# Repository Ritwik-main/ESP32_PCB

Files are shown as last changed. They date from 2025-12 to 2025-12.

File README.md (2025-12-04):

# ESP32_PCB
DesignESP32PCB

# A pcb using espressif ESP32-S3-DEV
This project involves making a devboard using the ESP32-s3 module by Espressif.
We know ESP are the go-to microcontrollers when we want speed and integrated Wifi Bluetooth in out projects.








# Features
1. Fully designed in KiCad
2. Features a USB-C USB 2.0 for convenience
3. ESP32 DevBoard features a design under 100*100mm, making it ideal for production houses.
4. 2-Layer PCB
5. Built in AdaFruit NeoPixel as an actuator
6. Built in Zero-PCB/protoboard with ~600 holes to make deployment after prorotype as easy as it can get!

# Main components used
1. Espressif ESP32-S3-Mini-N8
2. Adafruit Neopixel 5mm
3. Texas Instruments tlv758p
4. USB-C 2.0

# Schematic
Designed in KiCad


# resources I used for this project:
1. https://docs.espressif.com/projects/esp-hardware-design-guidelines/en/latest/esp32s3/esp-hardware-design-guidelines-en-master-esp32s3.pdf
2. https://docs.espressif.com/projects/esp-idf/en/stable/esp32s3/get-started/index.html
3. https://www.ti.com/lit/ds/symlink/tlv758p.pdf?ts=1764750861284
4. https://documentation.espressif.com/esp32-s3_technical_reference_manual_en.pdf
5. https://cdn-shop.adafruit.com/datasheets/WS2812B.pdf

# Developer note:
If you do manufacture this PCB, when you get it for the first time, it is necessary to do the initialization boot sequence when esp is powered.
hold boot> click reset once> release boot
This allows ESP to go into coding mode where you can upload code into your board.

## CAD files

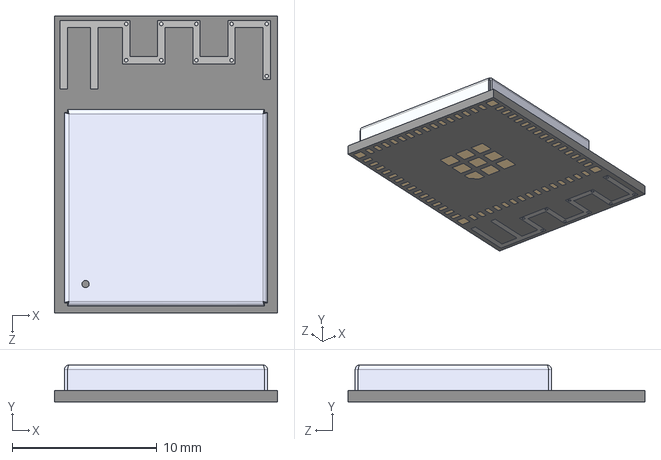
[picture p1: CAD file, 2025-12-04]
ESP32_S3_MINI_1_N8/ESP32-S3-MINI-1-N8.step
15.4 x 2.55 x 20.5 mm

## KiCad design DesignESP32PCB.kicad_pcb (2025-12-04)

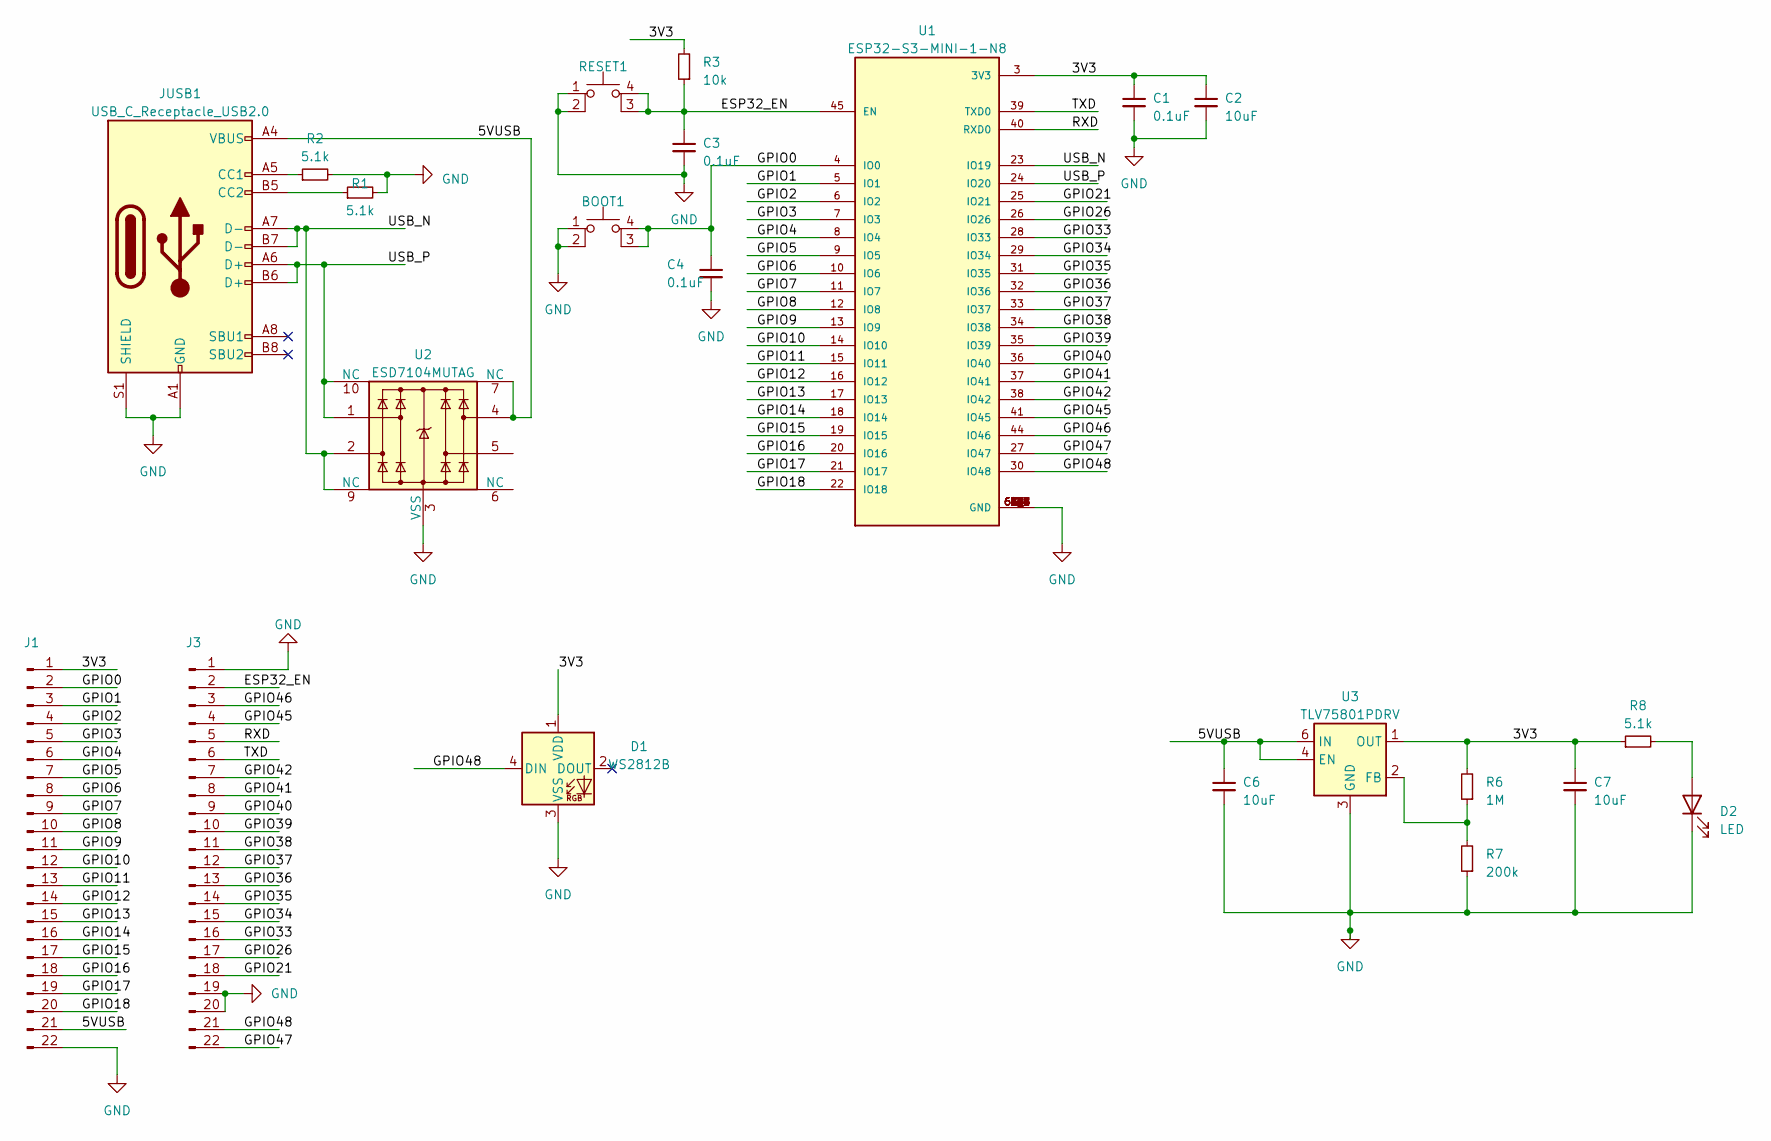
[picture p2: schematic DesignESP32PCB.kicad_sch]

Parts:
BOOT1: SW_SPST_PTS810
C1, C3, C4: 0.1uF; C_0603_1608Metric
C2, C6, C7: 10uF; C_0603_1608Metric
D1: WS2812B; LED_WS2812B_PLCC4_5.0x5.0mm_P3.2mm
D2: LED; LED_0603_1608Metric
J1, J3: PinHeader_1x22_P2.54mm_Vertical
JUSB1: USB_C_Receptacle_USB2.0; USB_C_Receptacle_GCT_USB4105-xx-A_16P_TopMnt_Horizontal
R1, R2, R8: 5.1k; R_0603_1608Metric
R3: 10k; R_0603_1608Metric
R6: 1M; R_0603_1608Metric
R7: 200k; R_0603_1608Metric
RESET1: SW_SPST_PTS810
U1: ESP32-S3-MINI-1-N8; XCVR_ESP32-S3-MINI-1-N8; PARTREV v0.6
U2: ESD7104MUTAG; Diodes_UDFN-10_1.0x2.5mm_P0.5mm
U3: TLV75801PDRV; WSON-6-1EP_2x2mm_P0.65mm_EP1x1.6mm

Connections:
/3V3: C1.1, C2.1, C7.1, D1.1 (VDD), J1.1, R3.2, R6.2, R8.1, U1.3 (3V3), U3.1 (OUT)
/5VUSB: C6.1, J1.21, JUSB1.A4 (VBUS), JUSB1.A9 (VBUS), JUSB1.B4 (VBUS), JUSB1.B9 (VBUS), U2.4, U2.7 (NC), U3.4 (EN), U3.6 (IN)
/ESP32_EN: C3.1, J3.2, R3.1, RESET1.3 (K), RESET1.4 (A), U1.45 (EN); also elsewhere on the board
/GPIO0: BOOT1.3 (K), BOOT1.4 (A), C4.1, J1.2, U1.4 (IO0); also elsewhere on the board
/GPIO1: J1.3, U1.5 (IO1)
/GPIO2: J1.4, U1.6 (IO2)
/GPIO3: J1.5, U1.7 (IO3)
/GPIO4: J1.6, U1.8 (IO4)
/GPIO5: J1.7, U1.9 (IO5)
/GPIO6: J1.8, U1.10 (IO6)
/GPIO7: J1.9, U1.11 (IO7)
/GPIO8: J1.10, U1.12 (IO8)
/GPIO9: J1.11, U1.13 (IO9)
/GPIO10: J1.12, U1.14 (IO10)
/GPIO11: J1.13, U1.15 (IO11)
/GPIO12: J1.14, U1.16 (IO12)
/GPIO13: J1.15, U1.17 (IO13)
/GPIO14: J1.16, U1.18 (IO14)
/GPIO15: J1.17, U1.19 (IO15)
/GPIO16: J1.18, U1.20 (IO16)
/GPIO17: J1.19, U1.21 (IO17)
/GPIO18: J1.20, U1.22 (IO18)
/GPIO21: J3.18, U1.25 (IO21)
/GPIO26: J3.17, U1.26 (IO26)
/GPIO33: J3.16, U1.28 (IO33)
/GPIO34: J3.15, U1.29 (IO34)
/GPIO35: J3.14, U1.31 (IO35)
/GPIO36: J3.13, U1.32 (IO36)
/GPIO37: J3.12, U1.33 (IO37)
/GPIO38: J3.11, U1.34 (IO38)
/GPIO39: J3.10, U1.35 (IO39)
/GPIO40: J3.9, U1.36 (IO40)
/GPIO41: J3.8, U1.37 (IO41)
/GPIO42: J3.7, U1.38 (IO42)
/GPIO45: J3.4, U1.41 (IO45)
/GPIO46: J3.3, U1.44 (IO46)
/GPIO47: J3.22, U1.27 (IO47)
/GPIO48: D1.4 (DIN), J3.21, U1.30 (IO48)
/RXD: J3.5, U1.40 (RXD0)
/TXD: J3.6, U1.39 (TXD0)
/USB_N: JUSB1.A7 (D-), JUSB1.B7 (D-), U1.23 (IO19), U2.2, U2.9 (NC)
/USB_P: JUSB1.A6 (D+), JUSB1.B6 (D+), U1.24 (IO20), U2.1, U2.10 (NC)
GND: BOOT1.1, BOOT1.2, C1.2, C2.2, C3.2, C4.2, C6.2, C7.2, D1.3 (VSS), D2.1 (K), J1.22, J3.1, J3.19, J3.20, JUSB1.A1 (GND), JUSB1.A12 (GND), JUSB1.B1 (GND), JUSB1.B12 (GND), JUSB1.S1 (SHIELD), R1.2, R2.2, R7.1, RESET1.1, RESET1.2, U1.1 (GND), U1.2 (GND), U1.42 (GND), U1.43 (GND), U1.46 (GND), U1.47 (GND), U1.48 (GND), U1.49 (GND), U1.50 (GND), U1.51 (GND), U1.52 (GND), U1.53 (GND), U1.54 (GND), U1.55 (GND), U1.56 (GND), U1.57 (GND), U1.58 (GND), U1.59 (GND), U1.60 (GND), U1.61 (GND), U1.61_1 (GND), U1.61_2 (GND), U1.61_3 (GND), U1.61_4 (GND), U1.61_5 (GND), U1.61_6 (GND), U1.61_7 (GND), U1.61_8 (GND), U1.62 (GND), U1.63 (GND), U1.64 (GND), U1.65 (GND), U2.3 (VSS), U2.8 (VSS), U3.3 (GND), U3.7 (GND); also elsewhere on the board
unnamed: D2.2 (A), R8.2
unnamed: JUSB1.A5 (CC1), R2.1
unnamed: JUSB1.B5 (CC2), R1.1
unnamed: R6.1, R7.2, U3.2 (FB)

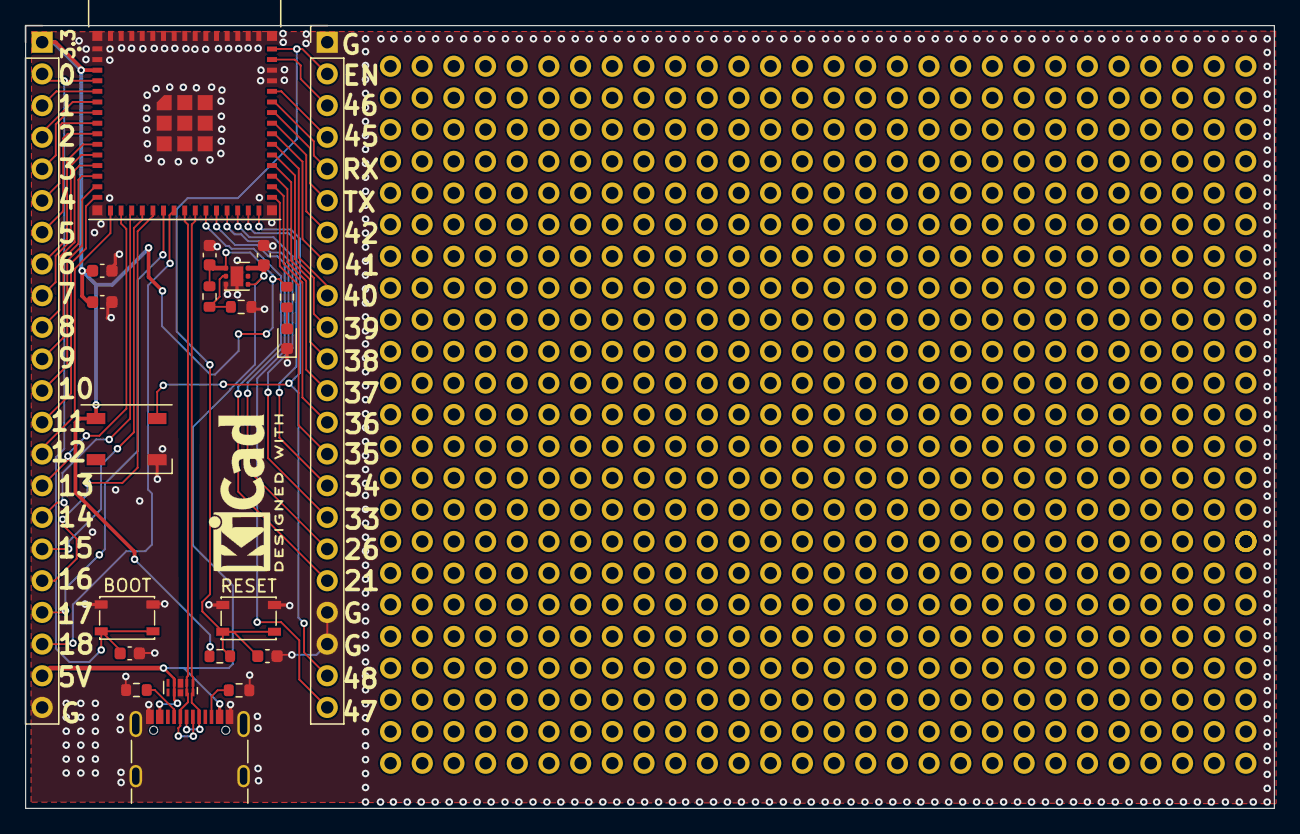
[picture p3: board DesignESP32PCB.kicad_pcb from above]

Board: 2 copper layers, 100.1 x 62.8 mm, 22 parts (0 on the bottom side), 47 nets.

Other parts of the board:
BOOT: SW_SPST_PTS810
RESET: SW_SPST_PTS810

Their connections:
/ESP32_EN: RESET.3 (K), RESET.4 (A); also elsewhere on the board
/GPIO0: BOOT.3 (K), BOOT.4 (A); also elsewhere on the board
GND: BOOT.1, BOOT.2, RESET.1, RESET.2; also elsewhere on the board
